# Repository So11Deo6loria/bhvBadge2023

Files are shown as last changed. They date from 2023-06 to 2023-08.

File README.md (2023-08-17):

# Introduction 
Badgetastic is a synergistic exercise in awesomeness for thrill seekers. Come one come all. Making a dope AF badge for BHV @ DEF CON 31. If you don't get the reference: https://www.youtube.com/watch?v=d0VO-zi5EgY

*Please be advised that the badge reader is solely intended for visualization purposes and should not be utilized to conduct any heart measurements intended for clinical or medical applications.*

# Prototyping
Here are the basic parts that were used during development of the badge: 
- [Raspberry Pi Pico](https://www.amazon.com/seeed-studio-Raspberry-Microcontroller-Dual-core/dp/B08TQSDP28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)
- [HR Monitor](https://www.amazon.com/dp/B07QC67KMQ?psc=1&ref=ppx_yo2ov_dt_b_product_details)
- [NeoPixel Array](https://www.amazon.com/dp/B00IEDH26K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)

Wiring: 
- HR Monitor (VIN/RPi3V3, GND/RPiGND, SCL/RPiGP17, and SDA/RPiGP16)
- LEDs (5VDC/RPiVSYS, GND/RPiGND, DIN/RPiGP15 or RPiGP22)

# Firmware Development
1. Download the MicroPython UF2 file: https://micropython.org/download/rp2-pico/rp2-pico-latest.uf2
1. Hold BOOTSEL while connecting to your computer via micro-USB cable
1. Device will reset and then you can use Thonny but it kind of stinks. I use Visual Studio Code for proper version control / IDE. 
1. Connect to the pico given the tty interface
`rshell -p /dev/tty.usbmodemXXXXXX --buffer-size 512`
1. Sync your local changes (assuming you have the firmware repo pulled down locally)
`rsync -m . /pyboard`
1. Connect to the REPL shell
`repl`
1. Soft reboot the pico to run main.py
`CTRL-D`
1. To exit you can press CTRL+C and to leave the repl shell you need to press CTRL+X

# Hardware Development
cadlab is cool: https://cadlab.io/project/26426/master/files

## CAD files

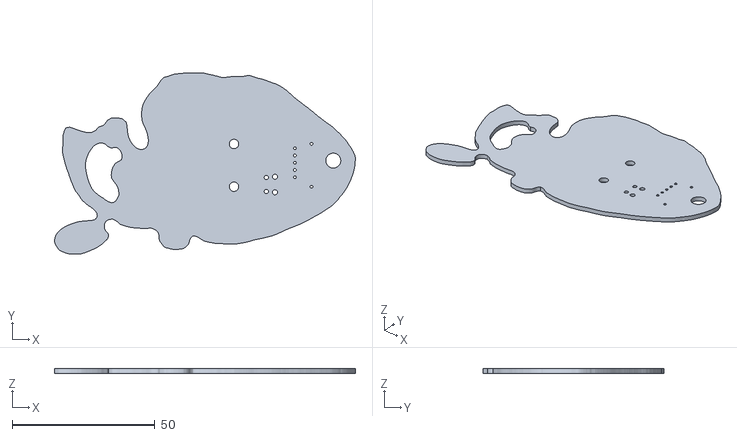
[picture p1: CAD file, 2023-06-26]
models/BoardModel.obj
105.5 x 63.6 x 1.60

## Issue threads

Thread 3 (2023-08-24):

Missing screw pegs

Aask42, 2023-08-24:
I'm experimenting with printing the heart in various translucent materials, and noticed the model of the heart is missing the peg-stands for mounting to the PCB. Any chance we could get an update that has a version of the heart with the screw holes in addition to this one? I can make one but if one already exists it just makes sense to aask :):

https://github.com/So11Deo6loria/bhvBadge2023/blob/main/models/HeartModel.tar.gz

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

heyfryman, 2023-08-24:
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

Apologies for not uploading the gasket STL for mounting the heart on the PCB.  I'll get that uploaded this afternoon.

heyfryman, 2023-08-25:
@Aask42
[BHV_Heart_Model.zip](https://github.com/So11Deo6loria/bhvBadge2023/files/12439606/BHV_Heart_Model.zip)

Attached is the heart model with the cavities for the screws. Unfortunately it is not a single object, but several objects that I still need to get merged into a single object. Once I'm able to get this merged into a single object, I'll make a post here.

**Important info about the model:**

1. This is PrusaSlicer (v2.6.0) 3mf file, which also contains the configuration information for a printer.
2. When you import the file into your slicer, you want to "Import 3D models only" 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
3. Select "OK"
4. Make sure you still have the correct printer and filament settings

Now you should be able to print the model correctly.

**Other info about the badge model:**

1. The screw cavities are designed for nylon 2.5M (~2.5mm diameter) screws that are 10mm in length.
2. When using TPU or other flexible material, we recommend using using a rod/screwdriver/Allen key or something similar to push into each cavity before inserting the screws to ensure it is clear of debris or any filament that could obstruct the path. If you print out of a non-flexible material you should tap each cavity with a 2.5M tap.
3.  Infill: We used 10% infill in a Lightning pattern, but we tested it with several different infills and they all worked. We chose Lightning at 10% infill because it prevented the light from calumniating.

Good luck and please share your results!

Aask42, 2023-08-25:
Getting this from prusaslicer to my ankermake has been a journey but we got it going! Will definitely show results of everything we try out once the print is complete in a few hours.

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

Aask42, 2023-08-25:
Oh before I foget, another note, the original model up here is also the wrong version of the file for fitting the final PCB:
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

heyfryman, 2023-08-25:
Thank you for information - we will get that model removed.

Aask42, 2023-08-25:
It looks great! Thank you for your help!

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

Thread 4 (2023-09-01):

Badge no longer turns on

Hnikar-az, 2023-09-01:
Hi,
So I started to notice a slight problem with the 2023 heart badge. After a few weeks turning on the badge it started to flicker with a very random pattern of lights. It looked like there might have been a short in the wiring as the LED lights were not in the standard sync'ed pattern and would run through multiple colors all across the badge. After removing the batteries and letting the badge stay unplugged for a few minutes it will no longer turn on.

Any pointers to how to troubleshoot this problem would be greatly appreciated. If this is the wrong place, pointers to the right place would also be helpful!

Hnikar-az, 2023-11-07:
The fix here is to change the batteries out. Badge works fine after this (I changed batteries multiple times, but I think I had old/bad ones)

Closed 2023-11-07.

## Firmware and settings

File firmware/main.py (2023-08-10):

import lowpower
import utime
import machine


import _thread
import constants
import prettyLights
import hrMonitor
import cerealInterface


import ujson


from machine import Pin, Timer, SoftI2C
class Main:
    def __init__(self):
        print("Start Up") # only print after receiving signal on Pin number DORMANT_PIN

        oldi2c1 = Pin(16,Pin.IN)
        oldi2c2 = Pin(17,Pin.IN)
        self.runLoop()

    def lowPowerPause(self):
        self.sensor.shutdown()
        self.leds.shutdown()
        while(self.button.value() != 1):
            utime.sleep_ms(10)
        lowpower.dormant_until_pin(constants.BUTTON)
        self.sensor.wakeUp()
        self.leds.wakeup()

    def startupAnimation(self):
        # self.sensor.setupSensor()
        self.leds.updateColorScheme(self.startupColor)
        self.leds.startupWave()
        self.leds.updateColorScheme(self.heartbeatColor)

    def read_config(self):
        try:
            with open('config.json', 'r') as f:
                data = ujson.load(f)
                return data
        except:
            return False
    def runLoop(self):

        config = self.read_config()
        if(config):
            print("Loading following configuration:")
            print(config)
            self.startupColor = config['startupColor']
            self.heartbeatColor = config['heartbeatColor']
            self.sleepTimeout = config['sleepTimeout']
        else:
            print("Loading default configuration")
            self.startupColor = 'heart',
            self.heartbeatColor = 'heart'
            self.sleepTimeout = 300 # 300 seconds


        self.button = Pin(constants.BUTTON, Pin.IN, Pin.PULL_UP)
        #self.button.irq(lambda e: print("button event!"), Pin.IRQ_FALLING)

        #startup Serial Interface
        serialInterface = cerealInterface.CerealInterface()
        _thread.start_new_thread(serialInterface.uartShell, ())

        #Initialize LED Manager and Turn on Power
        self.leds = prettyLights.LEDS()
        self.leds.wakeup()

        #Initialize HW for HR Sensor


        i2cHandle = SoftI2C(sda=Pin(constants.SDA_PIN), scl=Pin(constants.SCL_PIN), freq=constants.I2C_FREQ)
        self.sensor = hrMonitor.HRMonitor( i2cHandle, self.leds )

        #Give sensor time to come with a sexy animation
        self.leds.updateColorScheme(self.startupColor)
        self.leds.startupWave()
        self.leds.updateColorScheme(self.heartbeatColor)

        #Configure Sensor
        self.sensor.configureHRSensor()

        #Capture the Bootup Time
        startTime = utime.ticks_ms()

        while(True):
            currentTime = utime.ticks_ms()

            if((self.button.value() != 1) or (utime.ticks_diff(utime.ticks_ms(), startTime) > int(self.sleepTimeout)*1000)):
                print("getting sleepy")
                self.lowPowerPause()
                startTime = utime.ticks_ms()
                self.startupAnimation()

            self.sensor.hrRunLoop()
            self.leds.tickHeartbeat()
            utime.sleep_ms(10)

Main()

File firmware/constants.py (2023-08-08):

# Debug Flags
DEBUG = False
LED_TESTING = True
HR_TESTING = True

# Board Configuration
BUTTON = 5
SDA_PIN = 6
SCL_PIN = 7
OX_LED_PIN = 19
DEOX_LED_PIN = 18
PICO_LED_PIN = 25

# LED Constants
LED_INTENSITY = 255
BLINK_DELAY = 0.075 # Was 0.05
TROB_RATE  = 0.005
TROB_DELAY = 3
ERROR_DELAY = 3
LED_OFF = tuple([0, 0, 0])
LED_COUNT = 7
HEART_PATTERN = [0.1, 1, 0.1]
HEART_LED_INTENSITY = 255
CEREAL_DELAY = 0.075

#Serial/UART constants
CEREAL_TX_PIN = 12 #GPIO 12 Pin 16
CEREAL_RX_PIN = 13 # GPIO 13 Pin 17
BAUD_RATE = 115200

# HR Constants
I2C_FREQ = 100000

# Cereal Interface Constants
CEREAL_COLOR_SCHEMES = {
  'cinnamontoastcrunch': ['ce9958', '724705', 'd8d09f', 'b8732d', '9f633b'],
  'fruitypebbles': ['f0aa37', 'ffd52b', '00ffd7', '2edfb4', '10b990'],
  'luckycharms': ['216209', '8fac06', 'bdd9a3', '56a20d', '91d521'],
  'fruitloops': ['ff0000', 'ffe700', '7cff00', 'c900ff', '00dfff'],
  'applejacks': ['ffc360', 'fff4a3', 'e4a95d', '5caf4c', 'ff6254'],
  'trix': ['58e3ff', '87a2ff', 'af7ffc', 'da4e7d', 'f14848'], 
  'rainbow': ['ee82ee', '4b0082', '0000ff', '008000', 'ffff00', 'ffa500', 'ff0000']
}

# Old Junk Constants
HEART_RATE_SPAN = [10,250] # max span of heart rate
PTS = 1800 # points used for peak finding (400 Hz, I recommend at least 4s (1600 pts)
SMOOTHING_SIZE = 20 # convolution smoothing size
OFFSET = 0

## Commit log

2023-06-26 Initial code commit
    [BHV Power Calculation.xlsx, Badgetastic.kicad_pcb, Badgetastic.sch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]
2023-06-26 Compressing STL files.
    [BoardModel.stl]
2023-07-19 added cereal interface basic uart stuff
2023-07-24 Updated HR algorithm and fixed Nate's silly LED mistake.
    [autoFlasher.py, hrMonitor.py, main.py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]
2023-08-04 added LED when valid input; attempt to clean data
2023-08-06 updated HR, and integrated fixed for smooth rate changes in PrettyLights
    [hrMonitor.py, main.py, prettyLights.py]
2023-08-08 fixed timeout issue, added config json
    [main.py, prettyLights.py]
